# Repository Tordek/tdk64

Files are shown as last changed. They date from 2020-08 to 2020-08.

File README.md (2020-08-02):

TDK64 - a PIC-based USB adapter for N64 game pads
=================================================

You will need [Microchip MLA](https://www.microchip.com/mplab/microchip-libraries-for-applications) for the USB libraries.

The USB VID and PID have been chosen arbitrarily; they might cause conflicts that need to be resolved.

Warning
-------

This is an old project that I haven't updated in a while. `cheat.c` is not included because it's an easter egg that I implemented for my version.

It should work, from the last time I tested it. There is a KiCAD schematic included in the `n64` directory.

Have fun!

License
-------

This project is licensed under GNU GPL v3.0. See LICENSE.md for details.

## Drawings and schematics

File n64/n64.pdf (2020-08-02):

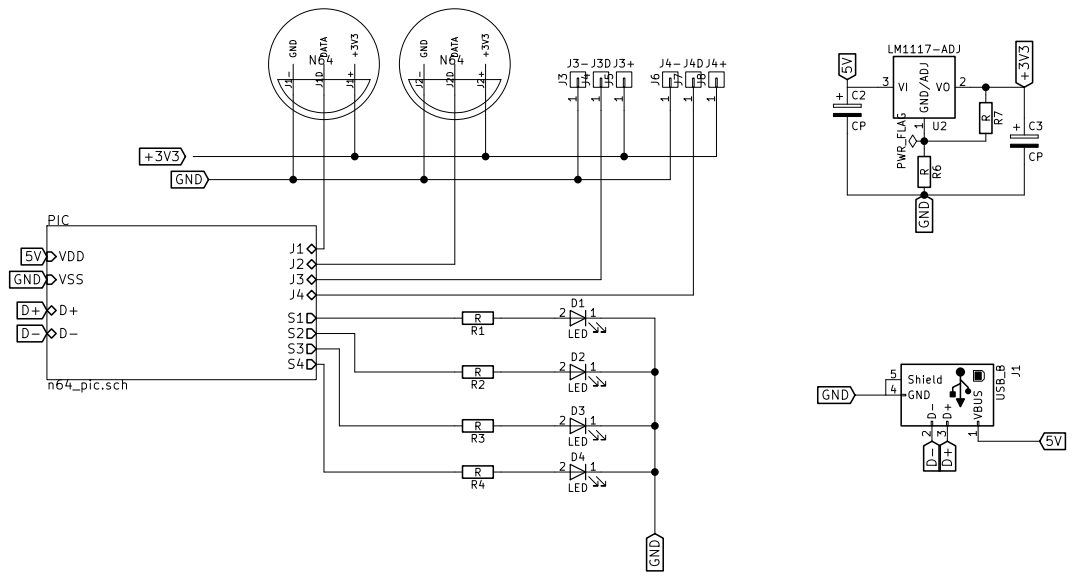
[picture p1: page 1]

Id: 1/2 Title: File: n64.sch Sheet: / VBUS

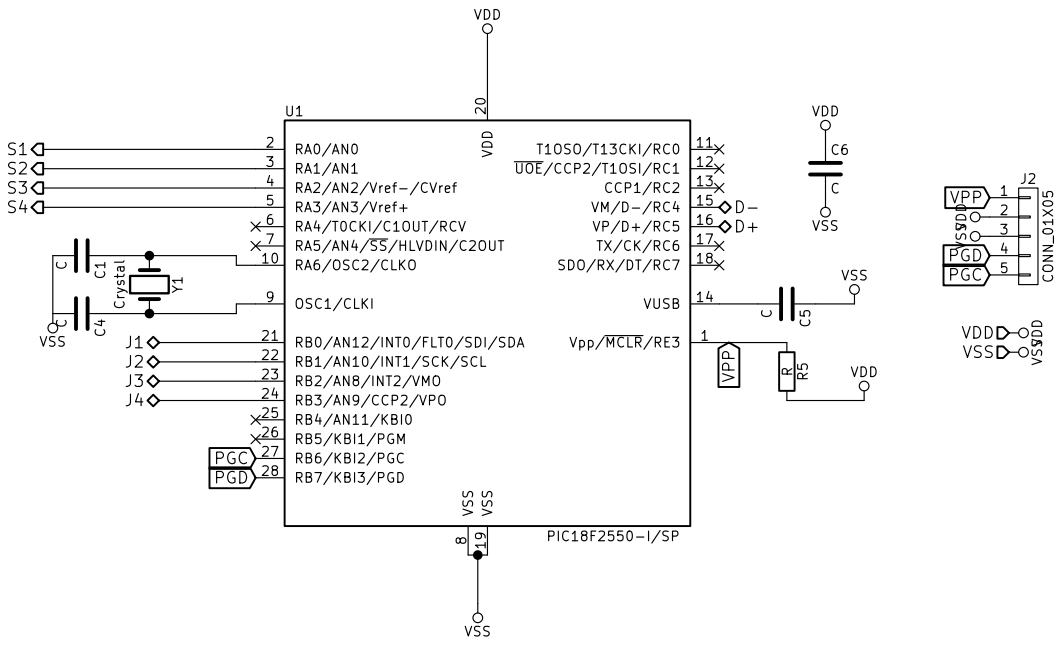
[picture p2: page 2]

8 OSC1/CLKI 9 RA6/OSC2/CLKO 10 VDD 20 T1OSO/T13CKI/RC0 11 RB0/AN12/INT0/FLT0/SDI/SDA 21 UOE/CCP2/T1OSI/RC1 12 RB1/AN10/INT1/SCK/SCL 22 CCP1/RC2 13 RB2/AN8/INT2/VMO 23 VUSB 14 RB3/AN9/CCP2/VPO 24 VM/D-/RC4 15 RB4/AN11/KBI0 25 VP/D+/RC5 16 RB5/KBI1/PGM 26 TX/CK/RC6 17 RB6/KBI2/PGC 27 SDO/RX/DT/RC7 18 RB7/KBI3/PGD 28 VSS 19 U1 PIC18F2550-I/SP

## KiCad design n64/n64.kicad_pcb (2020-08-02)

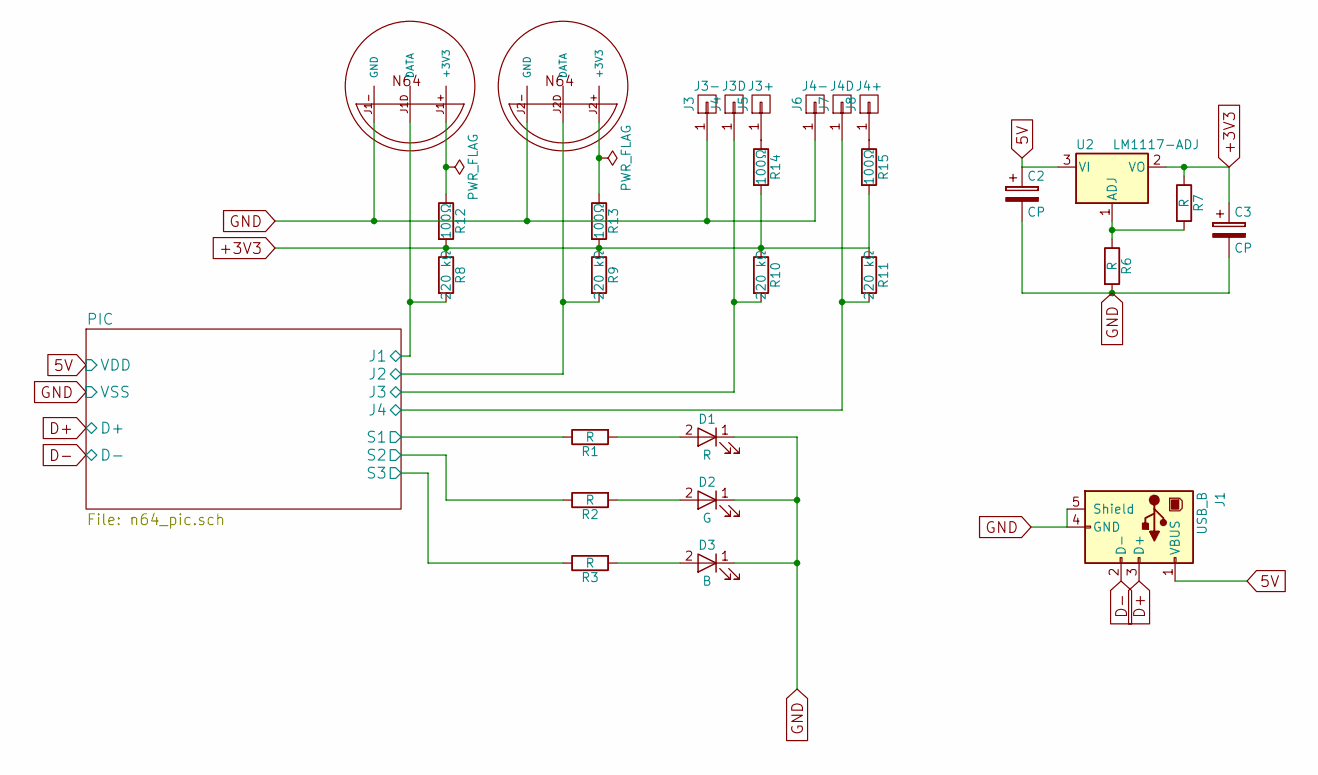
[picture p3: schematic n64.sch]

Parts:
C2, C3: CP; CP_Radial_D6.3mm_P2.50mm
D1: R; LED_Rectangular_W5.0mm_H2.0mm
D2: G; LED_Rectangular_W5.0mm_H2.0mm
D3: B; LED_Rectangular_W5.0mm_H2.0mm
J1: USB_B
J3: J3-; Pin_Header_Straight_1x01_Pitch2.54mm
J4: J3D; Pin_Header_Straight_1x01_Pitch2.54mm
J5: J3+; Pin_Header_Straight_1x01_Pitch2.54mm
J6: J4-; Pin_Header_Straight_1x01_Pitch2.54mm
J7: J4D; Pin_Header_Straight_1x01_Pitch2.54mm
J8: J4+; Pin_Header_Straight_1x01_Pitch2.54mm
M1: N64-PORT; n64-N64-DUAL-PORT-LEFT
R1, R2, R3, R6, R7: R; R_0805_HandSoldering
R8, R9, R10, R11: 220 kΩ; R_0805_HandSoldering
R12, R13, R14, R15: 100Ω; R_0805_HandSoldering
U2: LM1117-ADJ; SOT-223-3Lead_TabPin2

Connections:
5V: C2.1, J1.1 (VBUS), U2.3 (VI); also elsewhere on the board
+3V3: C3.1, R7.1, R8.1, R9.1, R10.1, R11.1, R12.2, R13.2, R14.2, R15.2, U2.2 (VO)
/PIC/J1: M1.J1D (DATA), R8.2; also elsewhere on the board
/PIC/J2: M1.J2D (DATA), R9.2; also elsewhere on the board
/PIC/J3: J4.1, R10.2; also elsewhere on the board
/PIC/J4: J7.1, R11.2; also elsewhere on the board
/PIC/S1: R1.1; also elsewhere on the board
/PIC/S2: R2.1; also elsewhere on the board
/PIC/S3: R3.1; also elsewhere on the board
D+: J1.3 (D+); also elsewhere on the board
D-: J1.2 (D-); also elsewhere on the board
GND: C2.2, C3.2, D1.1 (K), D2.1 (K), D3.1 (K), J1.4 (GND), J1.5 (Shield), J3.1, J6.1, M1.J1- (GND), M1.J2- (GND), R6.2; also elsewhere on the board
unnamed: D1.2 (A), R1.2
unnamed: D2.2 (A), R2.2
unnamed: D3.2 (A), R3.2
unnamed: J5.1, R14.1
unnamed: J8.1, R15.1
unnamed: M1.J1+ (+3V3), R12.1
unnamed: M1.J2+ (+3V3), R13.1
unnamed: R6.1, R7.2, U2.1 (ADJ)

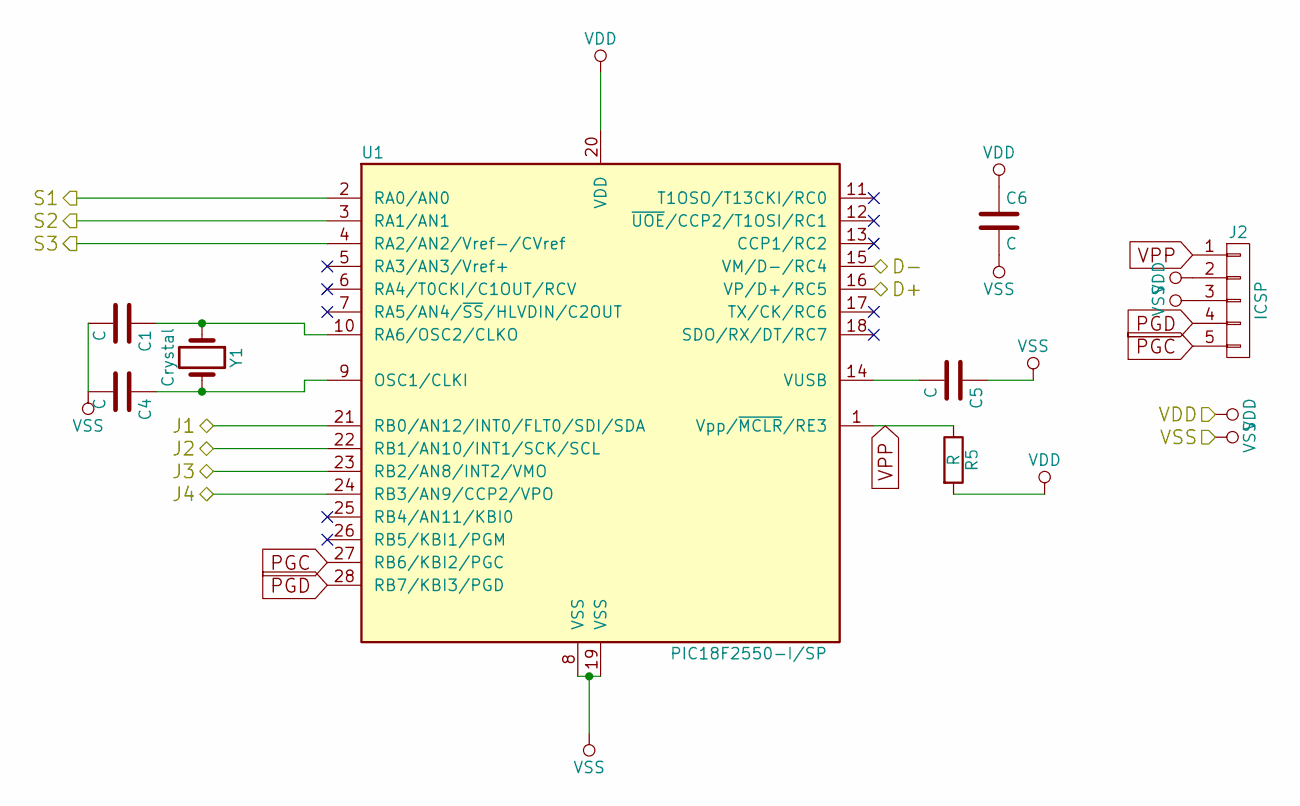
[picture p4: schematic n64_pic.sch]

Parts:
C1, C4, C5, C6: C; C_0805_HandSoldering
J2: ICSP; Pin_Header_Straight_1x05_Pitch2.54mm
R5: R; R_0805_HandSoldering
U1: PIC18F2550-I/SP; DIP-28_W7.62mm
Y1: Crystal; Crystal_HC49-4H_Vertical

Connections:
5V: C6.1, J2.2, R5.2, U1.20 (VDD); also elsewhere on the board
/PIC/J1: U1.21 (RB0/AN12/INT0/FLT0/SDI/SDA); also elsewhere on the board
/PIC/J2: U1.22 (RB1/AN10/INT1/SCK/SCL); also elsewhere on the board
/PIC/J3: U1.23 (RB2/AN8/INT2/VMO); also elsewhere on the board
/PIC/J4: U1.24 (RB3/AN9/CCP2/VPO); also elsewhere on the board
/PIC/S1: U1.2 (RA0/AN0); also elsewhere on the board
/PIC/S2: U1.3 (RA1/AN1); also elsewhere on the board
/PIC/S3: U1.4 (RA2/AN2/Vref-/CVref); also elsewhere on the board
D+: U1.16 (VP/D+/RC5); also elsewhere on the board
D-: U1.15 (VM/D-/RC4); also elsewhere on the board
GND: C1.2, C4.2, C5.1, C6.2, J2.3, U1.8 (VSS), U1.19 (VSS); also elsewhere on the board
unnamed: C1.1, U1.10 (RA6/OSC2/CLKO), Y1.1
unnamed: C4.1, U1.9 (OSC1/CLKI), Y1.2
unnamed: C5.2, U1.14 (VUSB)
PGC: J2.5, U1.27 (RB6/KBI2/PGC)
PGD: J2.4, U1.28 (RB7/KBI3/PGD)
VPP: J2.1, R5.1, U1.1 (Vpp/~MCLR~/RE3)

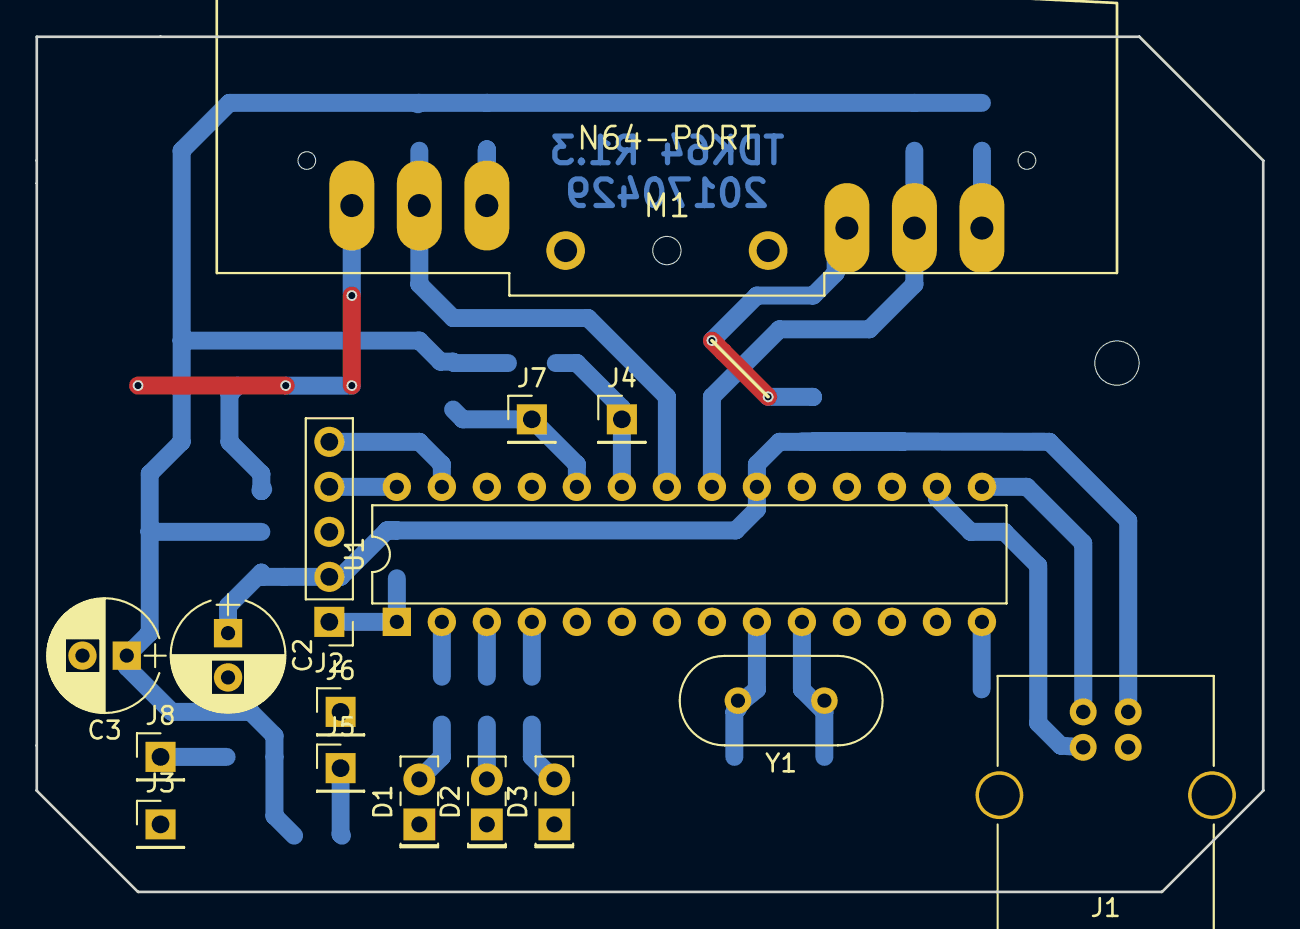
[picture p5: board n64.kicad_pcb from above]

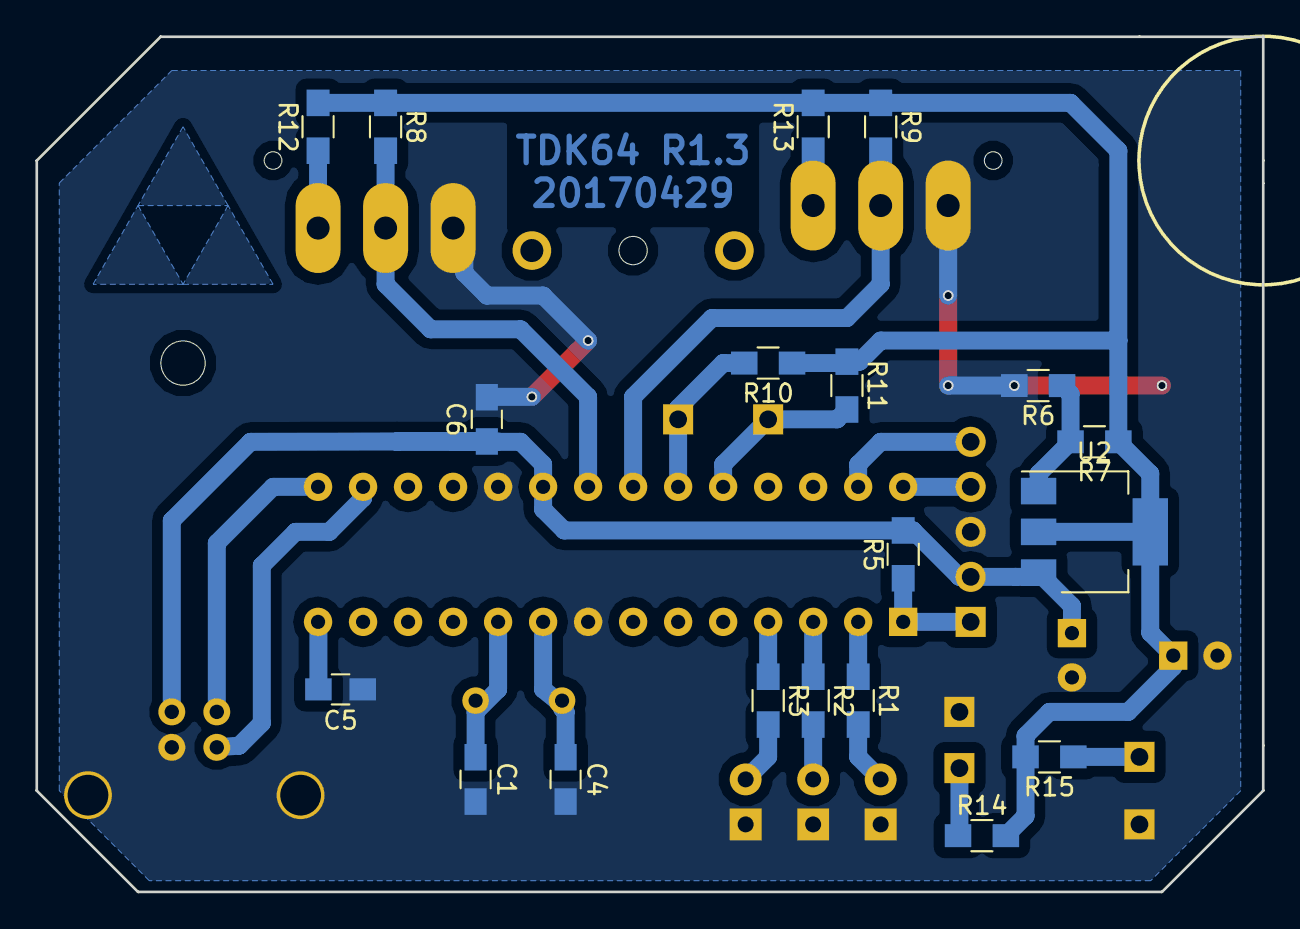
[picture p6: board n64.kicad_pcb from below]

Board: 2 copper layers, 69.2 x 48.3 mm, 35 parts (19 on the bottom side), 26 nets.

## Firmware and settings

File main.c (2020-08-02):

/*
 * Author: Guillermo O. «Tordek» Freschi
 * License: GNU GPL v3.0
 */

#define _XTAL_FREQ 24000000

#include <xc.h>

// CONFIG1L
#pragma config PLLDIV = 6       // PLL Prescaler Selection bits (Divide by 6 (24 MHz oscillator input))
#pragma config CPUDIV = OSC1_PLL2// System Clock Postscaler Selection bits ([Primary Oscillator Src: /1][96 MHz PLL Src: /2])
#pragma config USBDIV = 2       // USB Clock Selection bit (used in Full-Speed USB mode only; UCFG:FSEN = 1) (USB clock source comes directly from the primary oscillator block with no postscale)

// CONFIG1H
#pragma config FOSC = HS        // Oscillator Selection bits (HS oscillator (HS))
#pragma config FCMEN = OFF      // Fail-Safe Clock Monitor Enable bit (Fail-Safe Clock Monitor disabled)
#pragma config IESO = OFF       // Internal/External Oscillator Switchover bit (Oscillator Switchover mode disabled)

// CONFIG2L
#pragma config PWRT = OFF       // Power-up Timer Enable bit (PWRT disabled)
#pragma config BOR = ON         // Brown-out Reset Enable bits (Brown-out Reset enabled in hardware only (SBOREN is disabled))
#pragma config BORV = 3         // Brown-out Reset Voltage bits (Minimum setting 2.05V)
#pragma config VREGEN = ON      // USB Voltage Regulator Enable bit (USB voltage regulator enabled)

// CONFIG2H
#pragma config WDT = OFF        // Watchdog Timer Enable bit (WDT disabled)
#pragma config WDTPS = 32768    // Watchdog Timer Postscale Select bits (1:32768)

// CONFIG3H
#pragma config CCP2MX = ON      // CCP2 MUX bit (CCP2 input/output is multiplexed with RC1)
#pragma config PBADEN = OFF      // PORTB A/D Enable bit (PORTB<4:0> pins are configured as analog input channels on Reset)
#pragma config LPT1OSC = OFF    // Low-Power Timer 1 Oscillator Enable bit (Timer1 configured for higher power operation)
#pragma config MCLRE = ON       // MCLR Pin Enable bit (MCLR pin enabled; RE3 input pin disabled)

// CONFIG4L
#pragma config STVREN = ON      // Stack Full/Underflow Reset Enable bit (Stack full/underflow will cause Reset)
#pragma config LVP = OFF        // Single-Supply ICSP Enable bit (Single-Supply ICSP enabled)
#pragma config XINST = OFF      // Extended Instruction Set Enable bit (Instruction set extension and Indexed Addressing mode disabled (Legacy mode))

// CONFIG5L
#pragma config CP0 = OFF        // Code Protection bit (Block 0 (000800-001FFFh) is not code-protected)
#pragma config CP1 = OFF        // Code Protection bit (Block 1 (002000-003FFFh) is not code-protected)
#pragma config CP2 = OFF        // Code Protection bit (Block 2 (004000-005FFFh) is not code-protected)
#pragma config CP3 = OFF        // Code Protection bit (Block 3 (006000-007FFFh) is not code-protected)

// CONFIG5H
#pragma config CPB = OFF        // Boot Block Code Protection bit (Boot block (000000-0007FFh) is not code-protected)
#pragma config CPD = OFF        // Data EEPROM Code Protection bit (Data EEPROM is not code-protected)

// CONFIG6L
#pragma config WRT0 = OFF       // Write Protection bit (Block 0 (000800-001FFFh) is not write-protected)
#pragma config WRT1 = OFF       // Write Protection bit (Block 1 (002000-003FFFh) is not write-protected)
#pragma config WRT2 = OFF       // Write Protection bit (Block 2 (004000-005FFFh) is not write-protected)
#pragma config WRT3 = OFF       // Write Protection bit (Block 3 (006000-007FFFh) is not write-protected)

// CONFIG6H
#pragma config WRTC = OFF       // Configuration Register Write Protection bit (Configuration registers (300000-3000FFh) are not write-protected)
#pragma config WRTB = OFF       // Boot Block Write Protection bit (Boot block (000000-0007FFh) is not write-protected)
#pragma config WRTD = OFF       // Data EEPROM Write Protection bit (Data EEPROM is not write-protected)

// CONFIG7L
#pragma config EBTR0 = OFF      // Table Read Protection bit (Block 0 (000800-001FFFh) is not protected from table reads executed in other blocks)
#pragma config EBTR1 = OFF      // Table Read Protection bit (Block 1 (002000-003FFFh) is not protected from table reads executed in other blocks)
#pragma config EBTR2 = OFF      // Table Read Protection bit (Block 2 (004000-005FFFh) is not protected from table reads executed in other blocks)
#pragma config EBTR3 = OFF      // Table Read Protection bit (Block 3 (006000-007FFFh) is not protected from table reads executed in other blocks)

// CONFIG7H
#pragma config EBTRB = OFF      // Boot Block Table Read Protection bit (Boot block (000000-0007FFh) is not protected from table reads executed in other blocks)

#include <stdint.h>
#include <usb_device.h>
#include <usb_device_hid.h>

#include "n64_communications.h"
#include "cheat.h"

// The joystick can only be read so often; this variable is 1 whenever it can be.
volatile char read_enable = 0;
volatile int gamepad_connected = 0;

// Located in USB accessible memory

struct {
    char usb_report_id;

    union {
        char raw[4];
        struct n64_poll_response n64_response;
    };
} n64_usb_message @ 0x500;

// Handle to last transmission. Limits communication speed.
USB_VOLATILE USB_HANDLE last_transmission = NULL;

/**
 * Interrupt function. Triggered on TIMER1 overflow.
 *
 * TIMER1 triggers approximately every 1ms.
 */
void interrupt isr()
{
    if (PIR1bits.TMR1IF == 1) {
        read_enable++;
        PIR1bits.TMR1IF = 0;
        TMR1 = 5600; // 6MHz/60k = 100Hz.
    }
}

void main(void)
{
    // bool status_led = 0;
    int led_blink_timer = 0;

    // Enable TIMER1 interrupt.
    // TIMER1 2^16/6MHz = ~1ms
    TMR1IE = 1;
    PEIE = 1;
    GIE = 1;
    T1CONbits.RD16 = 1;
    T1CONbits.TMR1ON = 1;

    // Status LEDs.
    TRISA0 = 0;
    TRISA1 = 0;
    TRISA2 = 0;
    LATA = 0b00000001;

    // Joystick ports.
    LATB = 0;
    ADCON1 = 0x0F;
    TRISB = 0x0F;

    LATA2 = 1;
    GIE = 0;
    USBDeviceInit();
    USBDeviceAttach();
    GIE = 1;
    LATA2 = 1;

    for (;;) {
        GIE = 0;
        USBDeviceTasks();
        GIE = 1;

        if ((USBGetDeviceState() < CONFIGURED_STATE) ||
                USBIsDeviceSuspended()) {
            //Either the device is not configured or we are suspended,
            // so we don't want to execute any USB related application code
            continue;
        }

        if (read_enable < 1) {
            continue;
        }

        if (HIDTxHandleBusy(last_transmission)) {
            continue;
        }

        read_enable = 0;

        if (!gamepad_connected) {
            // Query command. Should return 05 00 01 or 05 00 02.
            char command[] = {0x00};
            char response[3];
            char rc = tdk64_command(0, command, 1, 0, response, 3);

            if (rc) {
                led_blink_timer -= rc;
                if (led_blink_timer <= 0) {
                    LATA2 = !LATA2;
                    led_blink_timer = 500;
                }
            } else {
                gamepad_connected = 1;
                LATA2 = 0;
            }
        } else {
            char command[1] = {0x01};
            char rc = tdk64_command(0, command, 1, 0, n64_usb_message.raw, 4);

            if (rc) {
                gamepad_connected = 0;
                memset(n64_usb_message.raw, 0, 5);
            } else {
                cheat(&n64_usb_message.n64_response);
                n64_usb_message.n64_response.analog_y = -n64_usb_message.n64_response.analog_y;
            }

            n64_usb_message.usb_report_id = 1;

            last_transmission = HIDTxPacket(HID_EP, (void *) &n64_usb_message, 5);
        }
    }
}

bool USER_USB_CALLBACK_EVENT_HANDLER(USB_EVENT event, void *pdata, uint16_t size)
{
    switch (event) {
    case EVENT_EP0_REQUEST:
        USBCheckHIDRequest();
        break;
    case EVENT_CONFIGURED:
        USBEnableEndpoint(HID_EP, USB_IN_ENABLED | USB_HANDSHAKE_ENABLED | USB_DISALLOW_SETUP);
        break;
    }

    return true;
}

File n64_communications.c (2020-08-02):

/*
 * Author: Guillermo O. «Tordek» Freschi
 * License: GNU GPL v3.0
 */

#include <xc.h>
#include <n64_communications.h>

static char tdk64_command_j1(char *send_buffer, char send_len, char wide_stop_bit, char *recv_buffer, char recv_len);
static char tdk64_command_j2(char *send_buffer, char send_len, char wide_stop_bit, char *recv_buffer, char recv_len);
static char tdk64_command_j3(char *send_buffer, char send_len, char wide_stop_bit, char *recv_buffer, char recv_len);
static char tdk64_command_j4(char *send_buffer, char send_len, char wide_stop_bit, char *recv_buffer, char recv_len);

/*
 * The N64 controller protocol sends all bits in a row, followed by a stop bit.
 * The signal is sent by changing the impedance of the pin, NOT by sending 5v.
 *
 * Each bit consists of some time of low signal, followed by some time of high
 * signal. If the bit is a 0, 3us of low are followed by 1 of high. If the bit
 * is a 1, 1us of low is followed by 3us of high.
 *
 * The controller responds quickly, so response has to be handled by the same
 * function.
 *
 * In order to pick the port, we need to do some preprocessor magic.
 */

char tdk64_command(char port, char *send_buffer, char send_len, char wide_stop_bit, char *recv_buffer, char recv_len)
{
    switch (port) {
    case 1:
        return tdk64_command_j1(send_buffer, send_len, wide_stop_bit, recv_buffer, recv_len);
    case 2:
        return tdk64_command_j2(send_buffer, send_len, wide_stop_bit, recv_buffer, recv_len);
    case 3:
        return tdk64_command_j3(send_buffer, send_len, wide_stop_bit, recv_buffer, recv_len);
    case 4:
        return tdk64_command_j4(send_buffer, send_len, wide_stop_bit, recv_buffer, recv_len);
    default:
        return 1;
    }
}

static char tdk64_command_j1(char *send_buffer, char send_len, char wide_stop_bit, char *recv_buffer, char recv_len)
{
#define WRITE_PORT "TRISB, 0"
#define READ_PORT "PORTB, 0"
#define SCOPE "tdk64_command_j1"
#include <n64_command.inc>
#undef WRITE_PORT
#undef READ_PORT
#undef SCOPE
}

static char tdk64_command_j2(char *send_buffer, char send_len, char wide_stop_bit, char *recv_buffer, char recv_len)
{
#define WRITE_PORT "TRISB, 1"
#define READ_PORT "PORTB, 1"
#define SCOPE "tdk64_command_j2"
#include <n64_command.inc>
#undef WRITE_PORT
#undef READ_PORT
#undef SCOPE
}

static char tdk64_command_j3(char *send_buffer, char send_len, char wide_stop_bit, char *recv_buffer, char recv_len)
{
#define WRITE_PORT "TRISB, 2"
#define READ_PORT "PORTB, 2"
#define SCOPE "tdk64_command_j3"
#include <n64_command.inc>
#undef WRITE_PORT
#undef READ_PORT
#undef SCOPE
}

static char tdk64_command_j4(char *send_buffer, char send_len, char wide_stop_bit, char *recv_buffer, char recv_len)
{
#define WRITE_PORT "TRISB, 3"
#define READ_PORT "PORTB, 3"
#define SCOPE "tdk64_command_j4"
#include <n64_command.inc>
#undef WRITE_PORT
#undef READ_PORT
#undef SCOPE
}
